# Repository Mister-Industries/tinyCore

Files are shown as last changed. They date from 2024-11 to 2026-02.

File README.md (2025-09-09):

# tinyCore - A Better Way to Learn ESP32

<div align="center">




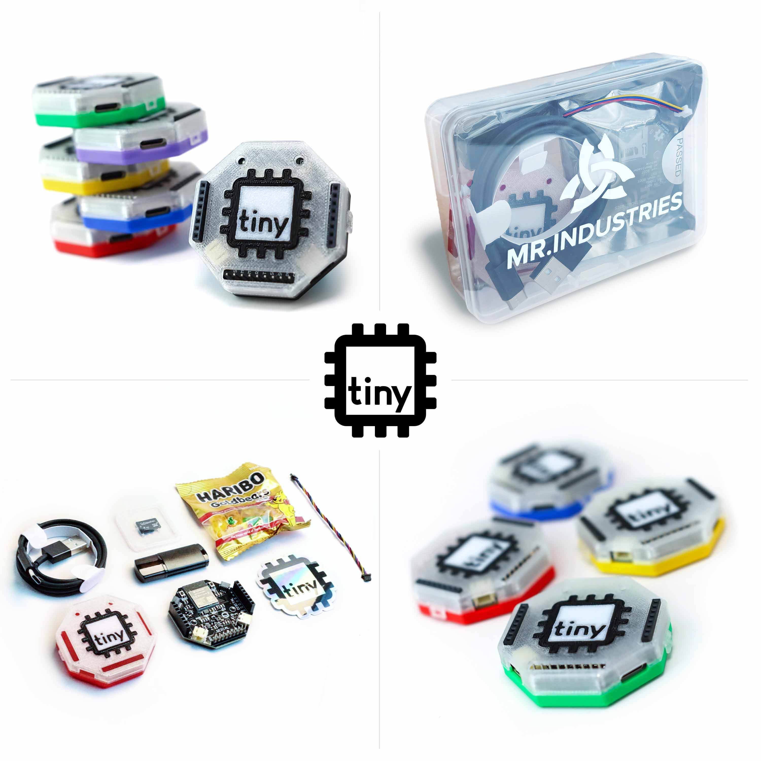
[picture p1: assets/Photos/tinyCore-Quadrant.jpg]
tinyCore Photos


</div>

ESP32-S3 chips are manufactured by Espressif®.
> Espressif® is a trademark of Espressif Systems (Shanghai) Co.Ltd (https://www.espressif.com/).

The tinyCore ESP32-S3 Board can be programmed with the Arduino® IDE.
> Arduino® is a trademark of Arduino LLC (https://www.arduino.cc/).

## Overview
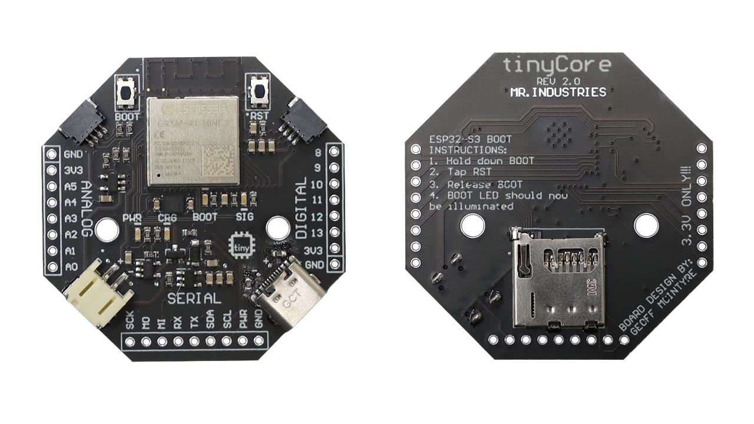
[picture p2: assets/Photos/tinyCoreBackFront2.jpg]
tinyCore Back/Front PCB


tinyCore is an engineering learning platform based around an "open-knowledge" microcontroller board designed to help educate individuals on the world of advanced embedded systems. tinyCore’s mission is to bridge the gap between undergrad and industry, equipping young professionals with the resources they need to build their portfolio and bring their ideas to life. 

## Pinout
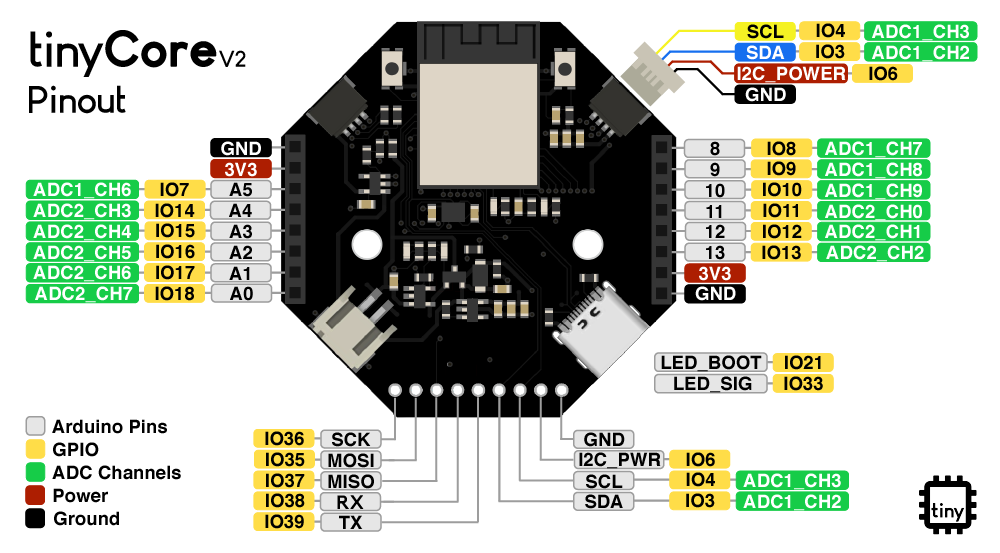
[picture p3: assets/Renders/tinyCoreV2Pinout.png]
tinyCore Pinout


### Key Features

- **Processor**: ESP32-S3 Mini Dual-Core No-PSRAM
- **Connectivity**: 
  - WiFi & Bluetooth LE
  - USB-C
  - 2x STEMMA/QWIIC I2C Connectors
  - Micro SD Card Slot
  - Built-in LSM6DSO IMU
- **Power**: 
  - USB-C powered
  - LiPo battery support with charging circuit
  - Low power sleep modes, Dedicated I2C PWR Rail
- **Dimensions**: 50mm x 50mm

## Getting Started

Open up the "START-HERE.pdf" document, or check out [our documentation](https://docs.mr.industries) to get started.

## Purchase

If you would like to get a tinyCore for yourself, please [visit our website](https://mr.industries/tiny-core) to purchase one!

For professors, tax-exempt organizations, or bulk orders (>10), please contact us through the following email address:
[support@mr.industries](mailto:support@mr.industries)

## Hardware

The complete hardware design files are available in the [hardware folder](https://github.com/Mister-Industries/tinyCore/tree/main/Hardware), including:
- Schematic files 
- PCB layout files (Altium/KiCad format)
- Bill of Materials (BOM)
- Manufacturing files (Gerber)
- Assembly instructions

## Development

### Contributing

We welcome contributions! Please see our [Contributing Guide](CONTRIBUTING.md) for details on:
- Code style guidelines
- Development workflow
- Testing requirements
- Pull request process

## Community

- [Discord Server](https://discord.gg/hvJZhwfQsF)
- [Bluesky](https://bsky.app/profile/mr.industries)

## License

This project is licensed under the MIT License - see the [LICENSE](LICENSE) file for details.

## Acknowledgments
The tinyCore project thrives thanks to the generous support of our manufacturing and development partners:
### --- PCBWay ---

PCBWay provides exceptional PCB manufacturing services and has been instrumental in bringing tinyCore to life through their reliable prototyping capabilities. You can order our open-source designs directly from [their website](https://www.pcbway.com/project/shareproject/iota_The_Open_Source_Advanced_IoT_Learning_Platform_12776757.html)

Special thanks to:
- The Adafruit team for inspiration
- All of our open source contributors
- "Prof. Eric Bogatin, Prof. Chris Coulston, Tyler Watts, Chaz Havens and countless others who inspired me to create fantastic things." - Geoff M.

## Support

MR.INDUSTRIES offers comprehensive technical support for everyone in our tinyCommunity:

* Help with understanding documentation and setup challenges
* Replacement parts for defective components
* Expert guidance for your tinyCore projects
* Weekly "Office Hours" every Thursday at 4:30 MST on [Discord Server](https://discord.gg/hvJZhwfQsF)
  * Get 1-1 help from our engineers via Discord voice
* Active community support through our [Discord](https://discord.gg/hvJZhwfQsF)

## Star History

Star History Chart (https://www.star-history.com/#Mister-Industries/tinyCore&Date)

You can also send us an email to:
[support@mr.industries](mailto:support@mr.industries)

**Our team is committed to helping you succeed with your project every step of the way.**

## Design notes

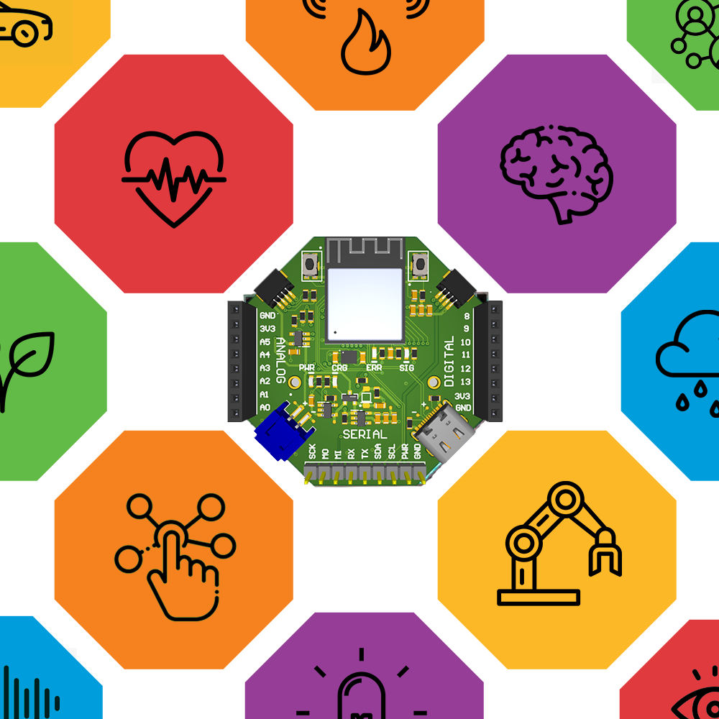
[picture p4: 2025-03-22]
assets/Renders/IotaKit.png

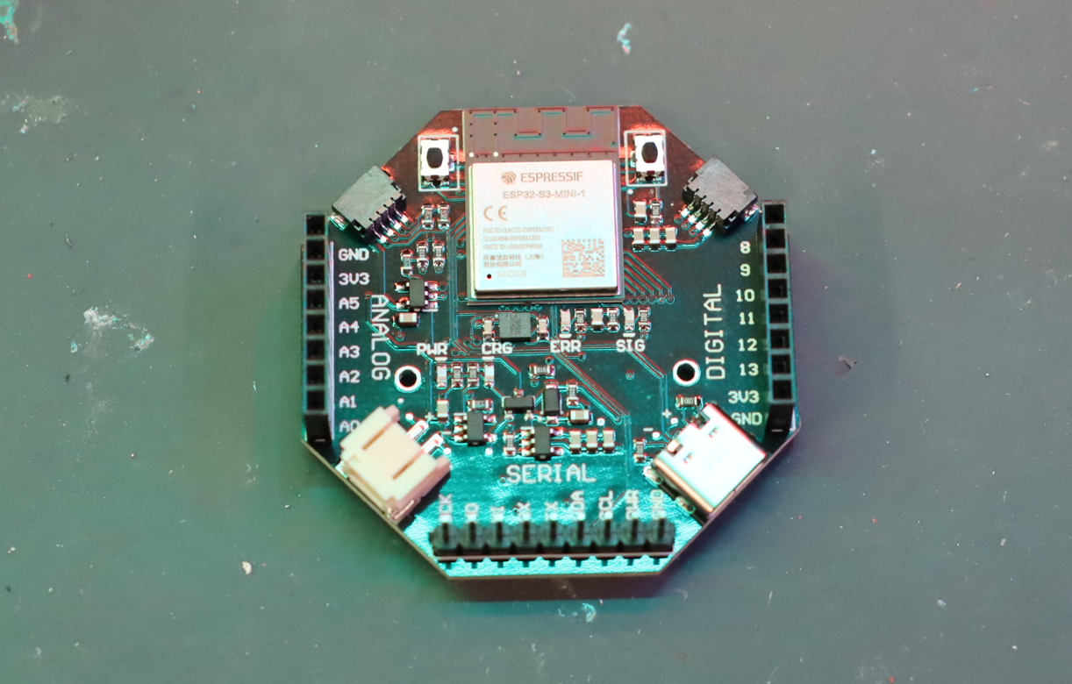
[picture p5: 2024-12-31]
assets/Photos/image.png

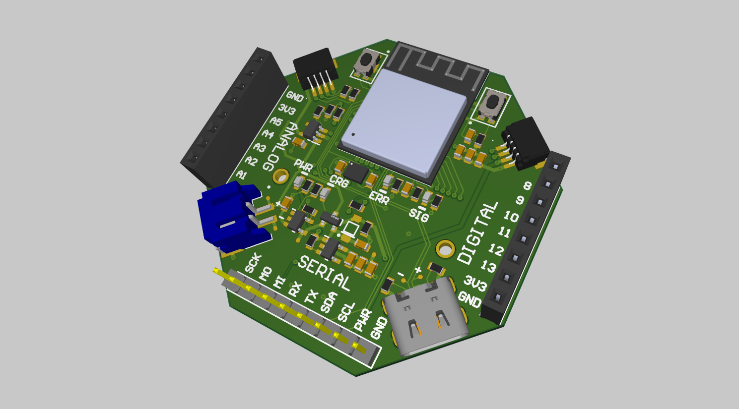
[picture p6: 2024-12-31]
assets/Renders/IotaCoreRenderWide.png

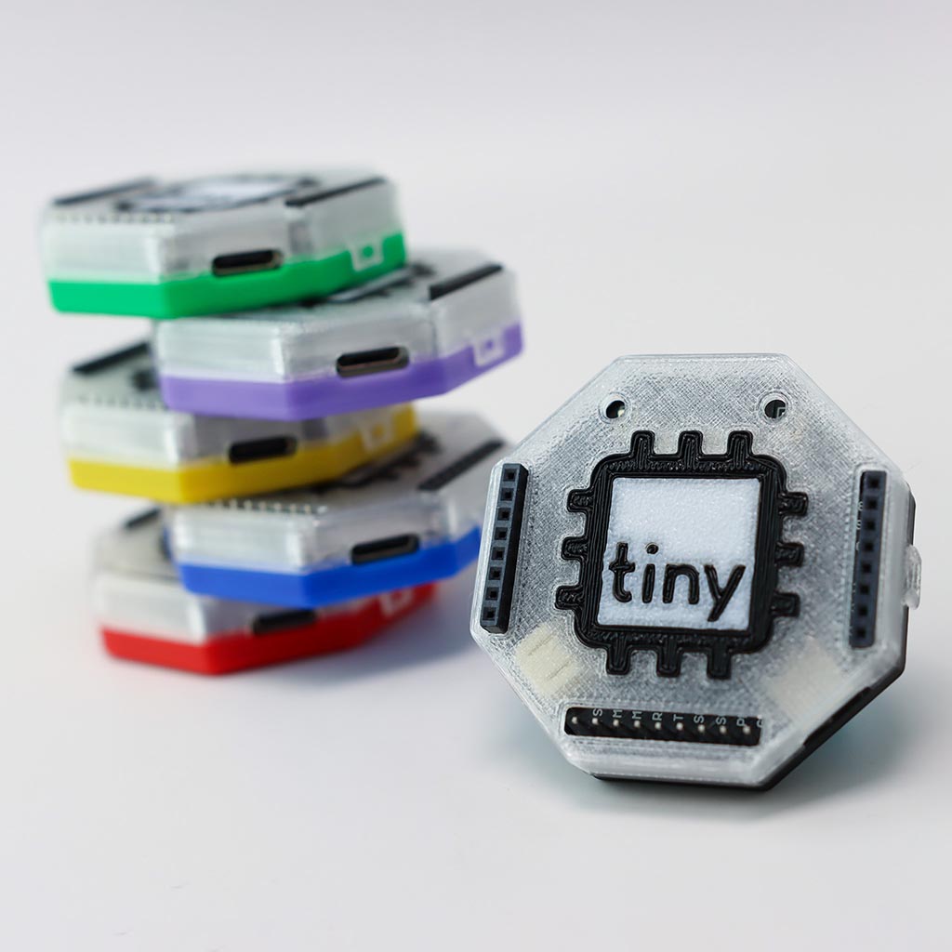
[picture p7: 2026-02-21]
assets/Photos/tinyCore-store-1.jpg

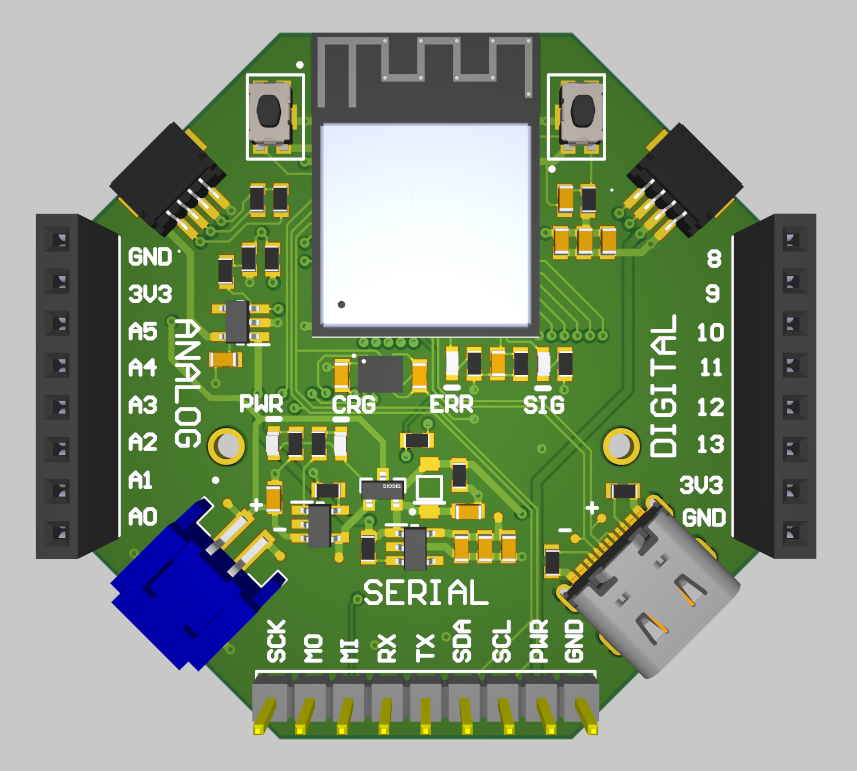
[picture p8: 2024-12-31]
assets/Renders/TopDown.png

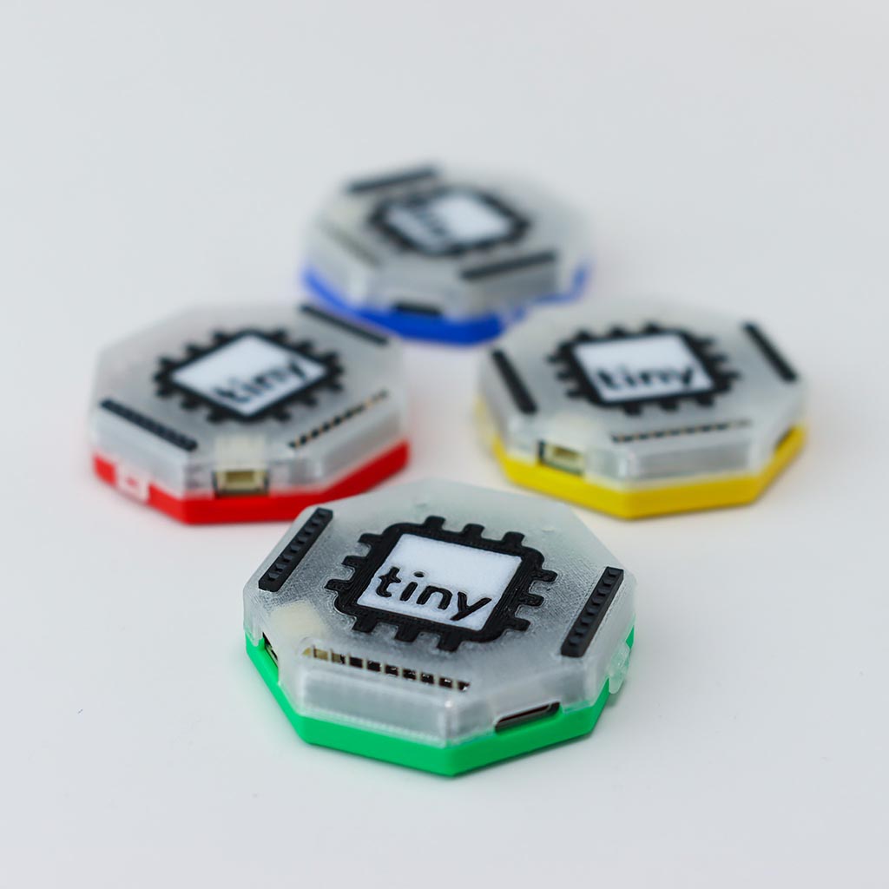
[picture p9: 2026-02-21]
assets/Photos/tinyCore-store-6.jpg

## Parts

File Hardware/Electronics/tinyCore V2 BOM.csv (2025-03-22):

Comment | Description | Designator | Footprint | LibRef | Quantity
LSM6DSOTR | DFD PROTECTION & FILTER | B1 | LSM6DSOTR | CMP-084-000000-2 | 1
AP2112K-3.3TRG1 | 600mA 3.3V LDO Regulator Enable SOT23-5 DiodesZetex AP2112K-3.3TRG1, LDO Voltage Regulator, 3.3 V +/-1.5%, 2.5 6 Vin, 5-Pin SOT-23 | B2, B4 | SOT95P270X145-5N | CMP-007-000001-1 | 2
MCP73831T-2ACI_OT | Li-Ion Charge Controller 4.2V SOT23-5 | B3 | SOT95P270X145-5N | CMP-009-000000-1 | 1
HSMA-C190 | LED Uni-Color Amber, 60 mW, 20 mA, -40 to 85 degC, 2-Pin SMD, RoHS, Tape and Reel | BOOT, CRG, PWR, SIG | AVAG-HSMX-C190_V | CMP-007-00011-2 | 4
Capacitor 10 uF +/- 0.25 uF 50 V 0603 | Chip Capacitor, 10 uF, +/- 0.25 uF, 50 V, 0603 (1608 Metric) | C1, C2, C3, C4, C7, C8, C9, C10, C11, C12, C13 | CAPC1608X87X35NL15T15 | CMP-001-00012-6 | 11
Capacitor 0.1 uF 50 V 0603 | Chip Capacitor, 0.1 uF, +/- 0.25 pF, 50 V, 0603 (1608 Metric) | C5, C6 | CAPC1608X87X35NL15T15 | CMP-001-00012-6 | 2
MBR120 | Diode | D1 | ONSC-SOD-123FL-2-498-01_V | CMP-004-00031-1 | 1
2908-05WB-MG | CONN MICRO SD CARD PUSH-PUSH R/A | J1 | FP-2908-05WB-MG-MFG | CMP-019-00049-1 | 1
USB4105-GF-A | USB-C 16-Pin Component | J5 | USB4105-GF-A | CMP-013-000000-1 | 1
4208 | Adafruit Accessories JST SH 4-pin Right Angle Connector (10-pack) - Qwiic Compatible | J6, J7 | 4390 | CMP-002-00080-4 | 2
CN-1P-2M-R2 |  | P1 | JST- S2B-PH-SM4-TB(LF)(SN)-2_V | CMP-005-000001-1 | 1
DMG2305UX-7 | Power Field-Effect Transistor, 4.2A I(D), 20V, 0.052ohm, 1-Element, P-Channel, Silicon, Metal-oxide Semiconductor FET | Q1 | FP-SOT23-MFG | CMP001-1 | 1
Resistor 100k +/-1% 0603 100 mW | Chip Resistor, 100 KOhm, +/- 1%, 0.1 W, -55 to 155 degC, 0603 (1608 Metric) | R1, R2, R7, R8, R9, R12 | RESC1608X55X25ML10T15 | CMP-009-00023-5 | 6
Resistor 4.7k +/-1% 0603 100 mW | Chip Resistor, 4.7 KOhm, +/- 1%, 0.1 W, -55 to 155 degC, 0603 (1608 Metric) | R3, R10, R13, R16, R17 | RESC1608X55X25ML10T15 | CMP-009-00023-5 | 5
Resistor 1k +/-1% 0603 100 mW | Chip Resistor, 1 KOhm, +/- 1%, 0.1 W, -55 to 155 degC, 0603 (1608 Metric) | R4, R5, R6, R11 | RESC1608X55X25ML10T15 | CMP-009-00023-5 | 4
Resistor 5.1k +/-1% 0603 100 mW | Chip Resistor, 5.1 KOhm, +/- 1%, 0.1 W, -55 to 155 degC, 0603 (1608 Metric) | R14, R15 | RESC1608X55X25ML10T15 | CMP-009-00023-5 | 2
KMR211GLFS |  | SW1, SW2 | FP-KMR211GLFS-MFG | CMP-011-00013-6 | 2
ESP32-S3-MINI-1-N8 | SMD module, ESP32-S3FN8, 8 MB SPI flash, PCB antenna | U1 | ESP32-S3-MINI-1-N8 | CMP-010-000006-5 | 1

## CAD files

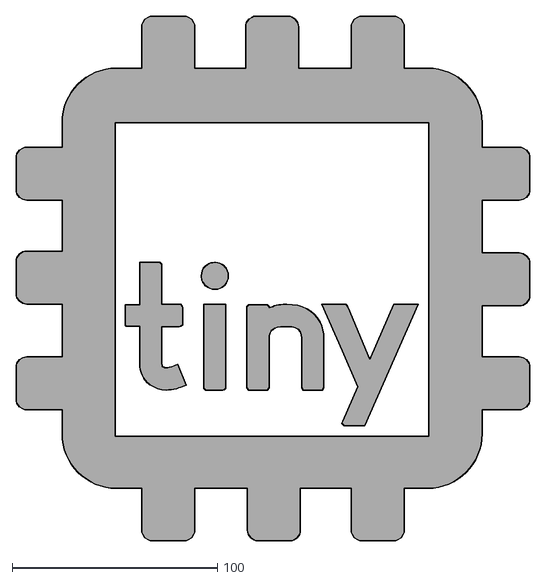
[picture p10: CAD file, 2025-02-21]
assets/Branding/tinyCore.dxf
250.1 x 255.3

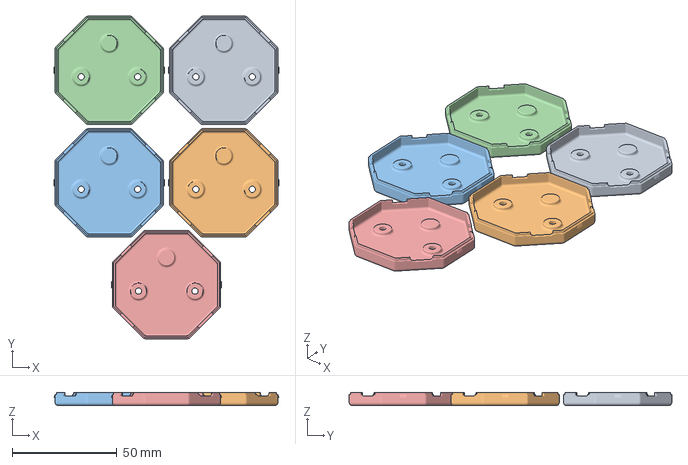
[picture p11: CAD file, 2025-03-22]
Hardware/Enclosure/Bambu/Enclosure-Bottom.3mf
107.6 x 154.3 x 6.30 mm
BottomEnclosureTabs.STL x 5

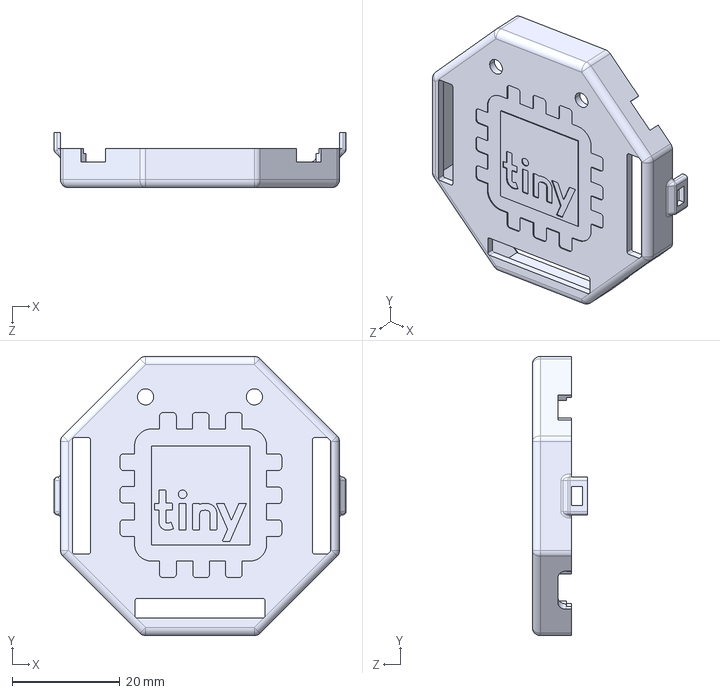
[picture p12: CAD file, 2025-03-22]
Hardware/Enclosure/STEP/Enclosure-Top.STEP
54.2 x 51.8 x 10.3 mm

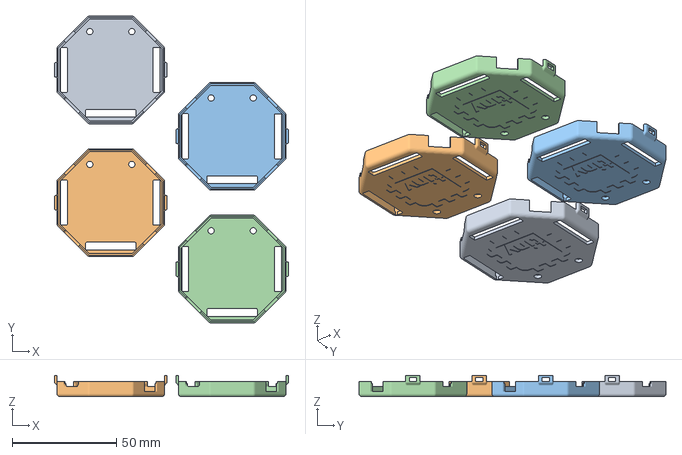
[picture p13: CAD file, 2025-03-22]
Hardware/Enclosure/Bambu/Enclosure-Top.3mf
112.5 x 147.5 x 10.3 mm
TopEnclosureLogo.STL x 4

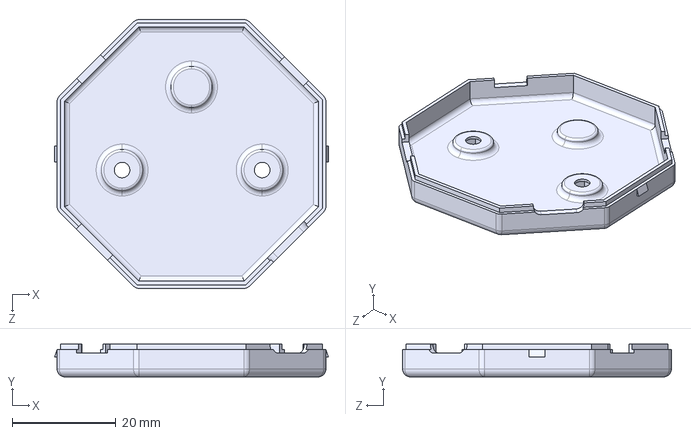
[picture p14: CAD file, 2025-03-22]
Hardware/Enclosure/STEP/Enclosure-Bottom.STEP
52.8 x 6.30 x 51.8 mm

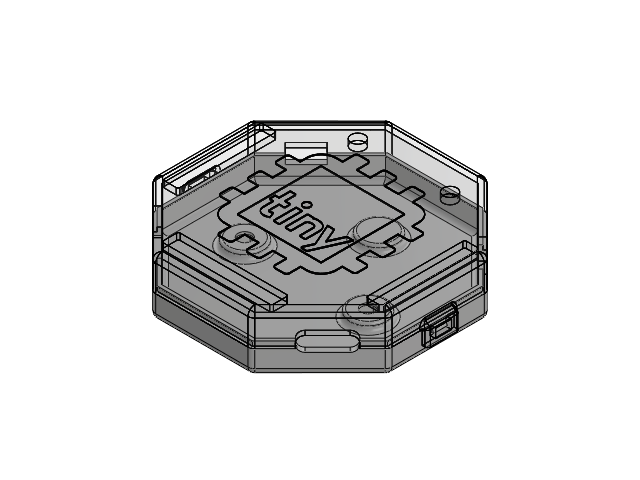
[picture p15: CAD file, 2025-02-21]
Hardware/Enclosure/SolidWorks/tinyCore.SLDASM
BottomEnclosure
TopEnclosure

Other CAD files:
Hardware/Enclosure/STL/Enclosure-Bottom.STL
Hardware/Enclosure/STL/Enclosure-Top.STL
Hardware/Enclosure/SolidWorks/Enclosure-Bottom.SLDPRT
Hardware/Enclosure/SolidWorks/Enclosure-Top.SLDPRT

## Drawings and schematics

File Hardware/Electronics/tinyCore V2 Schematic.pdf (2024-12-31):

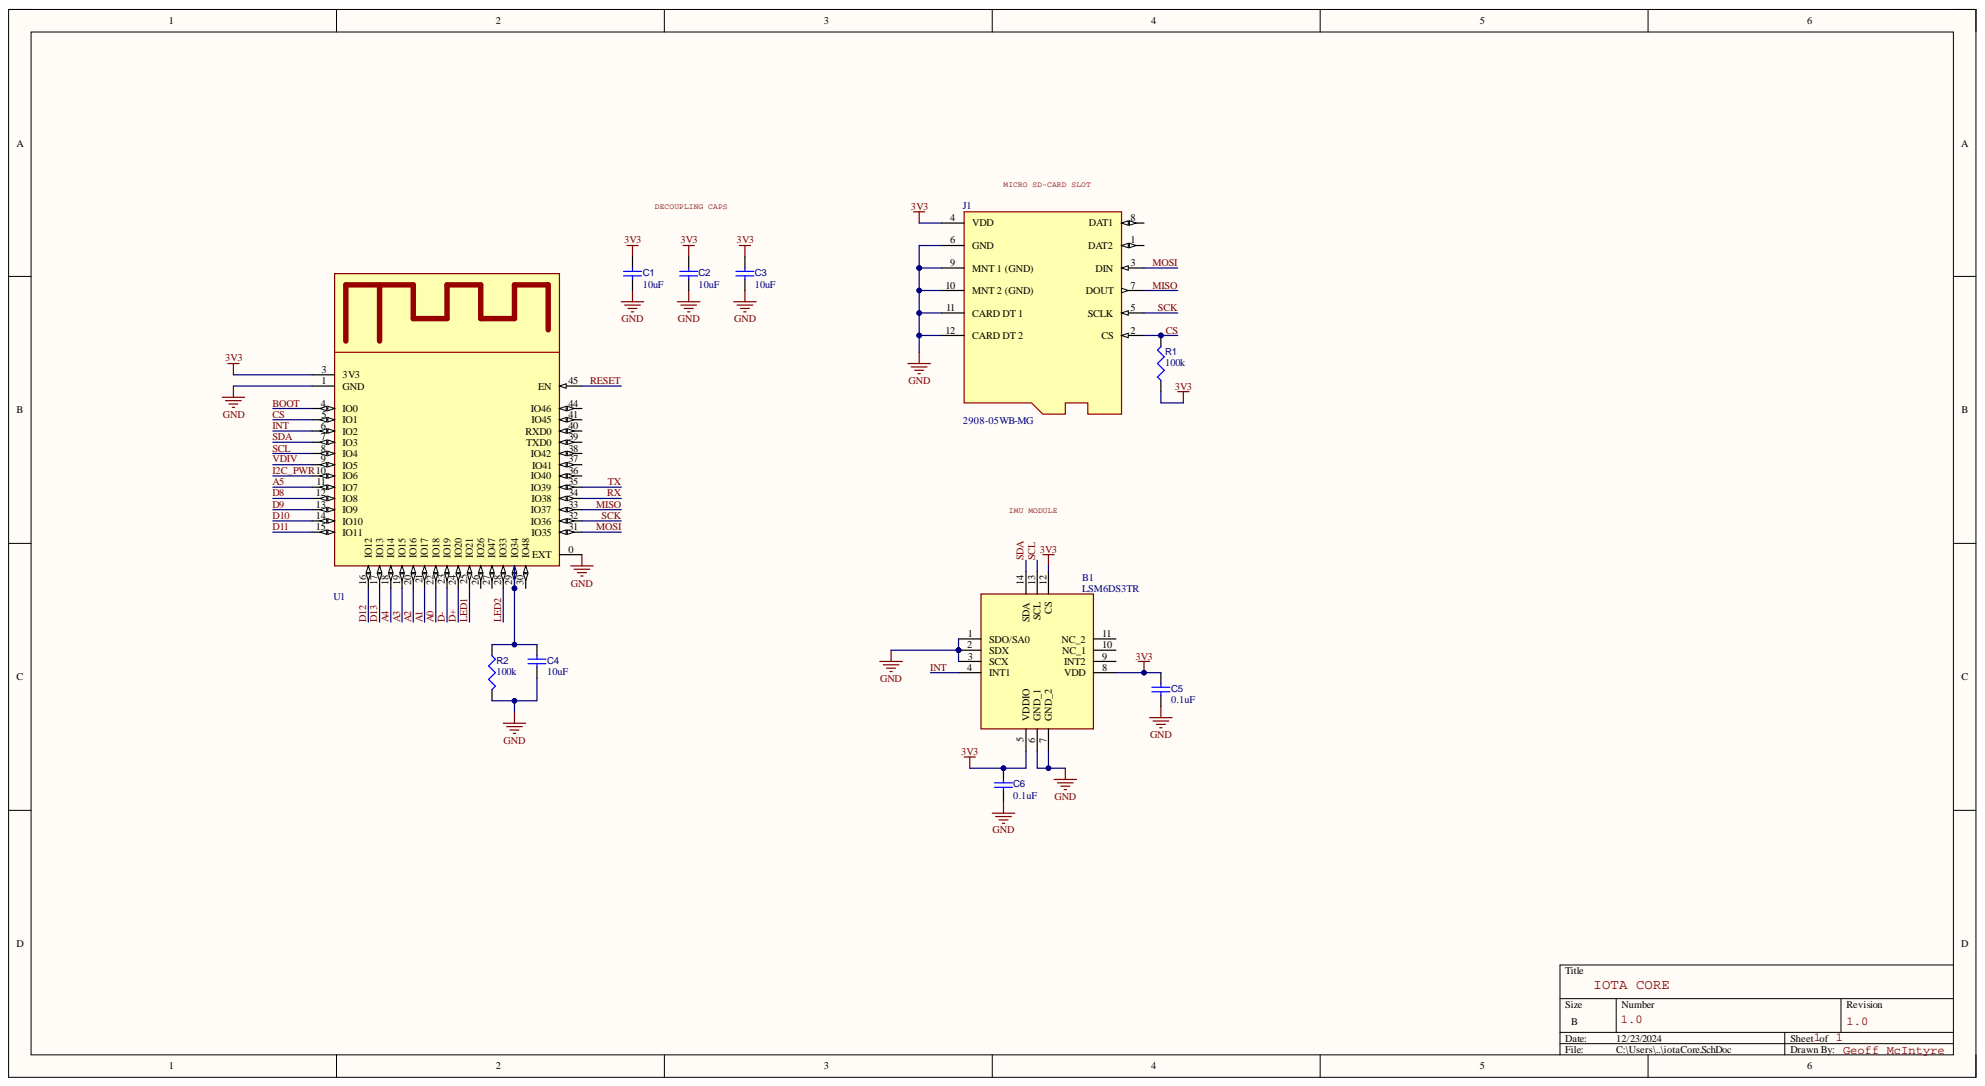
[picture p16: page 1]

te : 1 2 / 2 3 /2 0 2 4 | 1 1 S h e e t o f
Fi l e : C : \ U s e r s \ . . \ i o t a C o re . S c hDo c | D r a w n B y : Geoff McIntyre

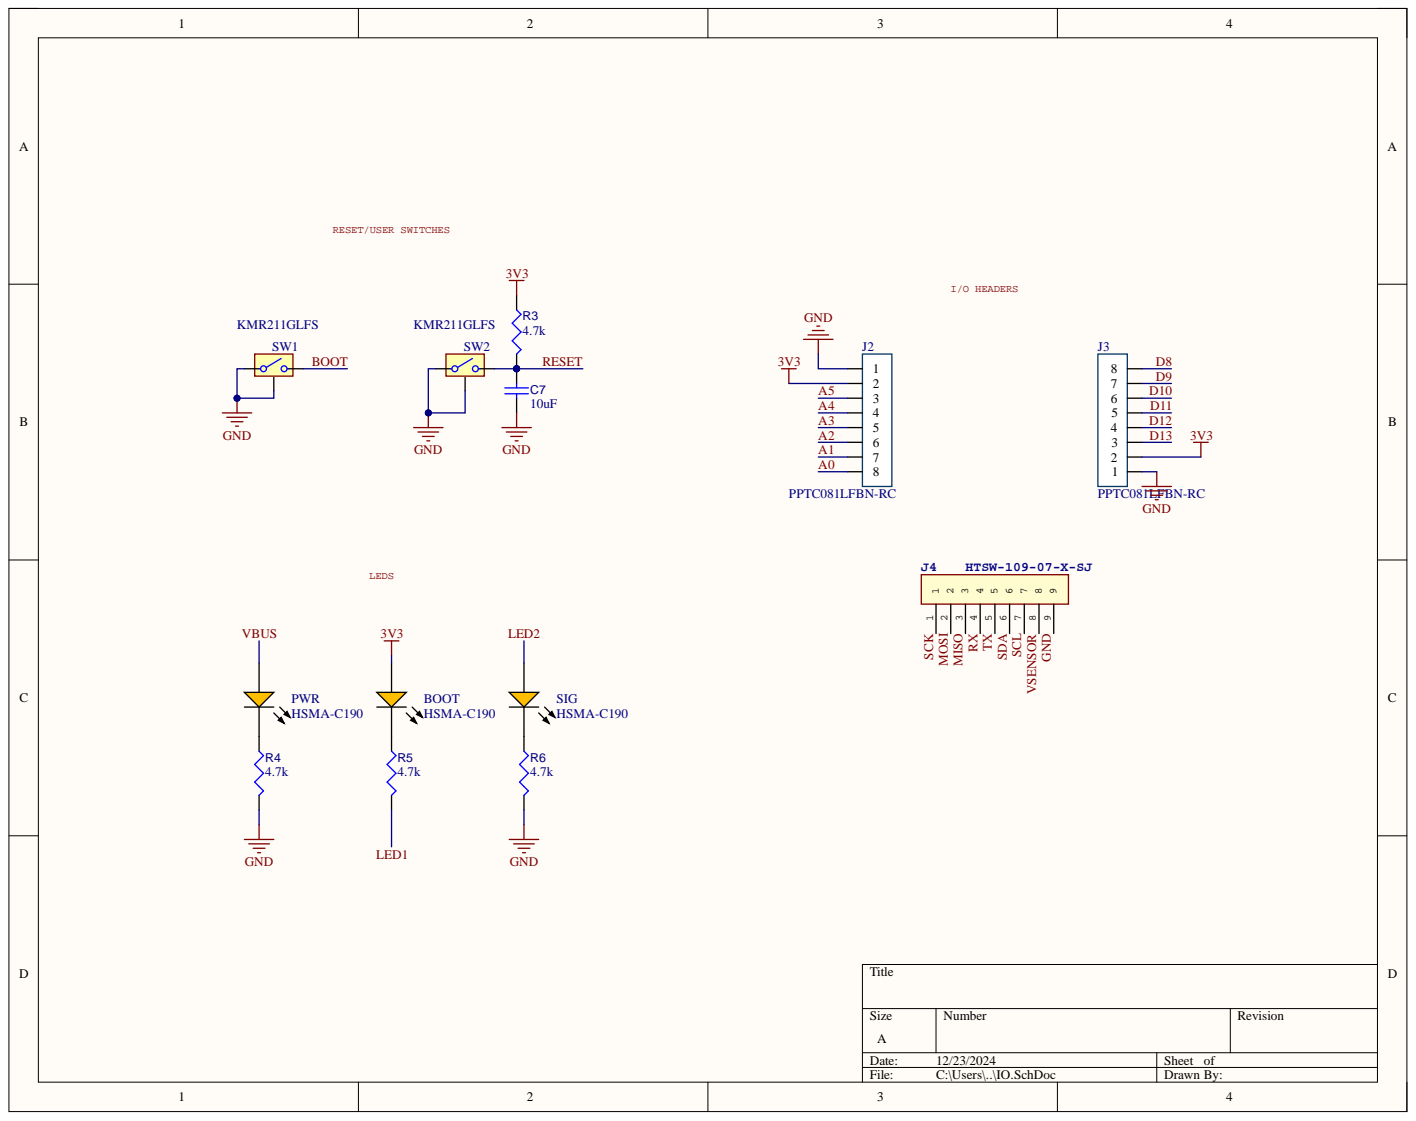
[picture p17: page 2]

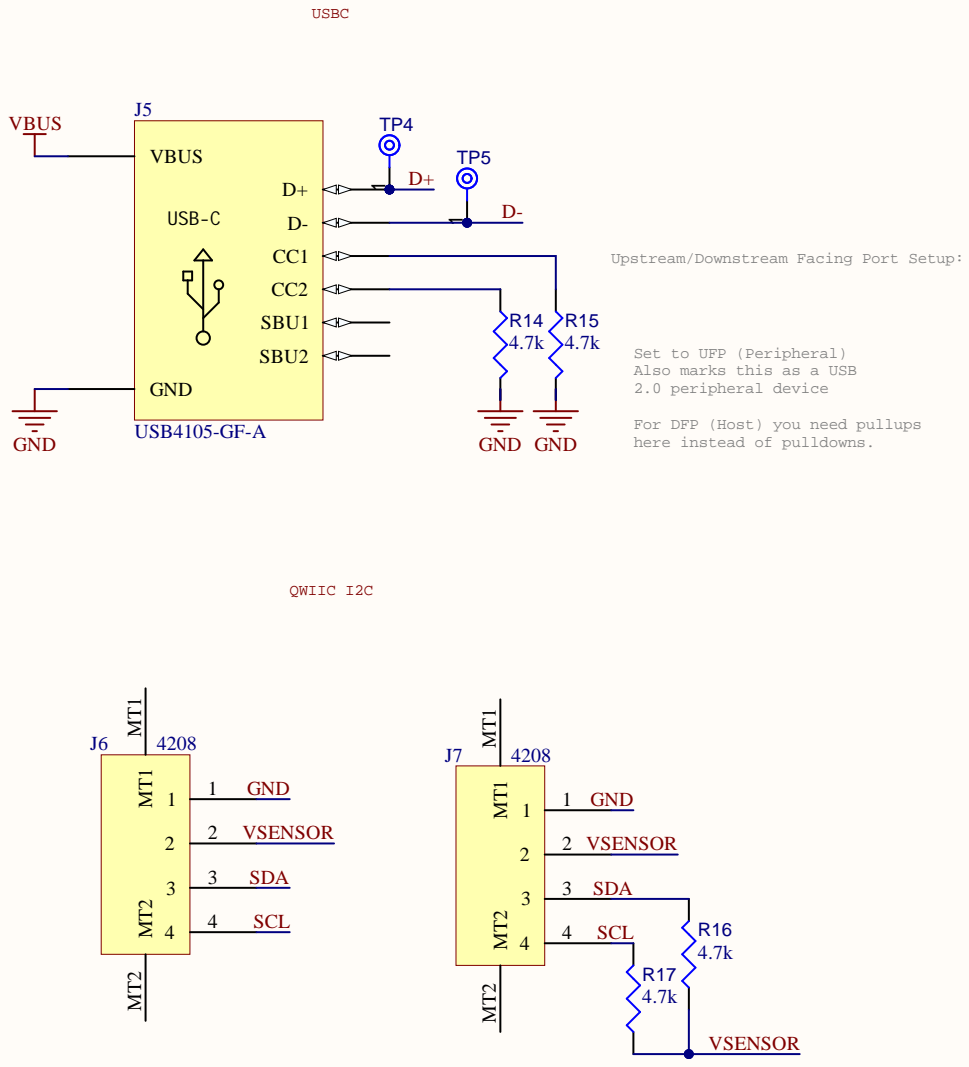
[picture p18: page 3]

Upstream/Downstream Facing Port Setup:

Set to UFP (Peripheral)
Also marks this as a USB
2.0 peripheral device

For DFP (Host) you need pullups
here instead of pulldowns.

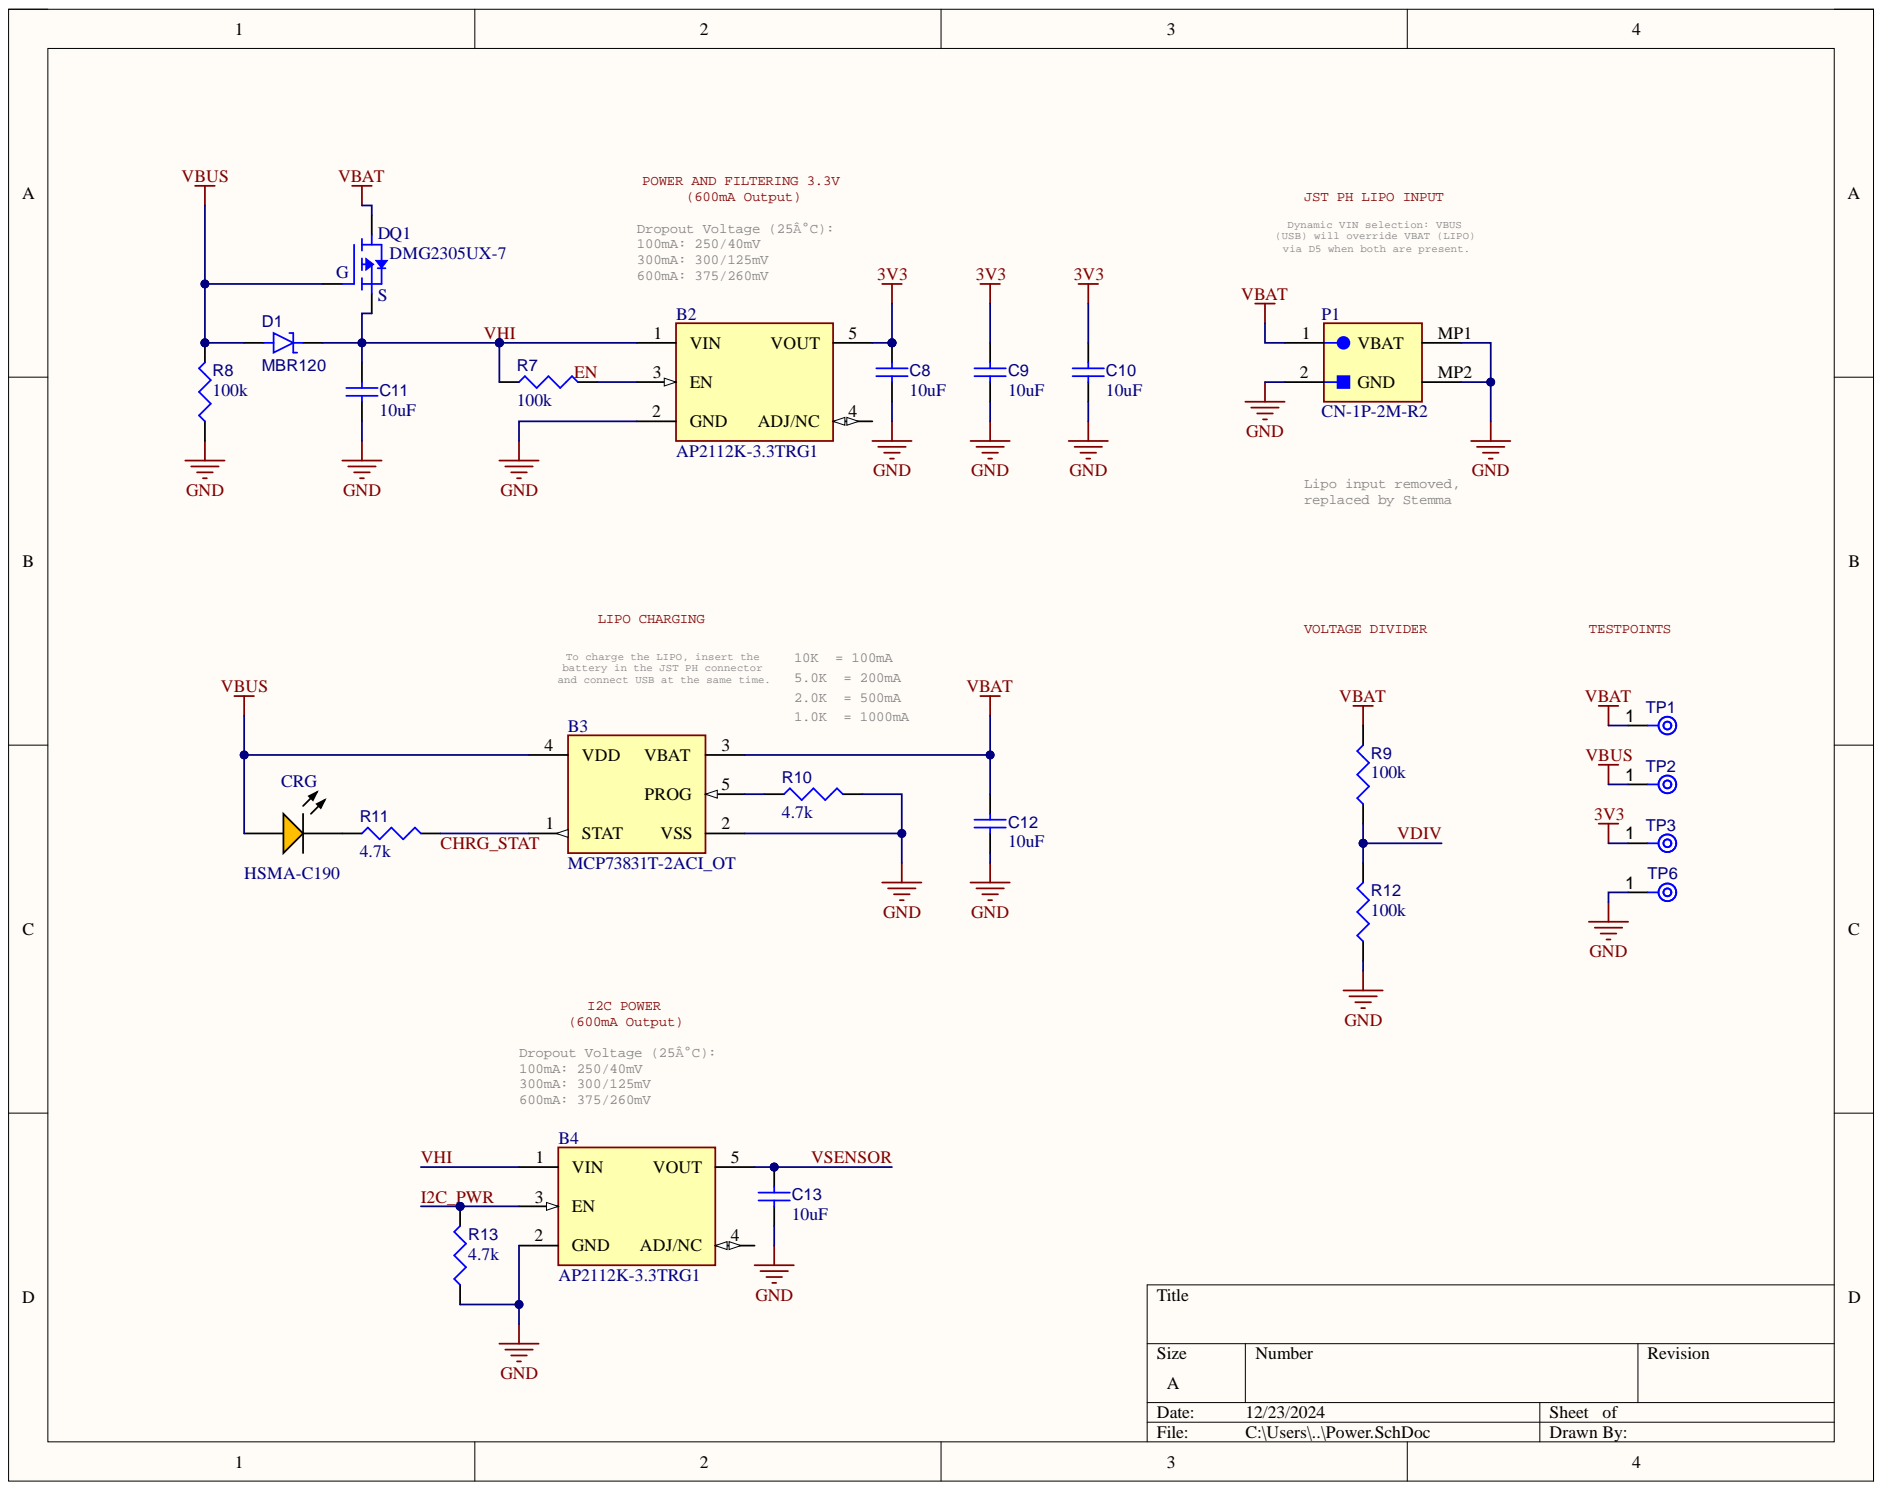
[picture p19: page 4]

JST PH LIPO INPUT

Dynamic VIN selection: VBUS
(USB) will override VBAT (LIPO)
via D5 when both are present.

To charge the LIPO, insert the
battery in the JST PH connector
and connect USB at the same time.

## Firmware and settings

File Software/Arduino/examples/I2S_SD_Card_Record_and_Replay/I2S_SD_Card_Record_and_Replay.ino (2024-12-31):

#include <Arduino.h>
#include "FS.h"
#include "SD.h"
#include "SPI.h"
#include <driver/i2s.h>

// Pin Definitions
// Microphone (SPH0645)
#define I2S_MIC_SCK     8
#define I2S_MIC_WS      9
#define I2S_MIC_SD      10

// Speaker
#define I2S_SPKR_BCLK   8
#define I2S_SPKR_LRC    9
#define I2S_SPKR_DIN    10

// Constants for recording
const int RECORD_TIME = 5;  // seconds to record
const int SAMPLE_RATE = 44100;
const int SAMPLE_BITS = 32;
const int WAV_HEADER_SIZE = 44;
const char* RECORD_FILE = "/recording.wav";
const int BINARY_BUFFER_SIZE = 1024;

// Global flag to track I2S state
bool i2s_initialized = false;

// WAV header structure
struct WavHeader {
    char riff[4] = {'R', 'I', 'F', 'F'};
    uint32_t fileSize = 0;
    char wave[4] = {'W', 'A', 'V', 'E'};
    char fmt[4] = {'f', 'm', 't', ' '};
    uint32_t fmtSize = 16;
    uint16_t audioFormat = 1;
    uint16_t numChannels = 1;
    uint32_t sampleRate = SAMPLE_RATE;
    uint32_t byteRate = SAMPLE_RATE * 2;
    uint16_t blockAlign = 2;
    uint16_t bitsPerSample = 16;
    char data[4] = {'d', 'a', 't', 'a'};
    uint32_t dataSize = 0;
};

void cleanup_i2s() {
    if (i2s_initialized) {
        i2s_stop(I2S_NUM_0);
        i2s_driver_uninstall(I2S_NUM_0);
        i2s_initialized = false;
        delay(100);
    }
}

void i2s_mic_init() {
    cleanup_i2s();
    
    // Configuration for SPH0645
    i2s_config_t i2s_config = {
        .mode = (i2s_mode_t)(I2S_MODE_MASTER | I2S_MODE_RX),
        .sample_rate = SAMPLE_RATE,
        .bits_per_sample = I2S_BITS_PER_SAMPLE_32BIT,
        .channel_format = I2S_CHANNEL_FMT_ONLY_LEFT,
        .communication_format = I2S_COMM_FORMAT_STAND_I2S,
        .intr_alloc_flags = ESP_INTR_FLAG_LEVEL1,
        .dma_buf_count = 4,
        .dma_buf_len = 1024,
        .use_apll = false,
        .tx_desc_auto_clear = false,
        .fixed_mclk = 0
    };
    
    i2s_pin_config_t pin_config = {
        .mck_io_num = I2S_PIN_NO_CHANGE,
        .bck_io_num = I2S_MIC_SCK,
        .ws_io_num = I2S_MIC_WS,
        .data_out_num = I2S_PIN_NO_CHANGE,
        .data_in_num = I2S_MIC_SD
    };
    
    esp_err_t err = i2s_driver_install(I2S_NUM_0, &i2s_config, 0, NULL);
    if (err != ESP_OK) {
        Serial.printf("Failed to install I2S driver for mic: %d\n", err);
        return;
    }
    
    err = i2s_set_pin(I2S_NUM_0, &pin_config);
    if (err != ESP_OK) {
        Serial.printf("Failed to set I2S pins for mic: %d\n", err);
        return;
    }
    
    i2s_initialized = true;
    delay(100);
}

void i2s_speaker_init() {
    cleanup_i2s();
    
    i2s_config_t i2s_config = {
        .mode = (i2s_mode_t)(I2S_MODE_MASTER | I2S_MODE_TX),
        .sample_rate = SAMPLE_RATE,
        .bits_per_sample = I2S_BITS_PER_SAMPLE_16BIT,
        .channel_format = I2S_CHANNEL_FMT_ONLY_LEFT,
        .communication_format = I2S_COMM_FORMAT_STAND_I2S,
        .intr_alloc_flags = ESP_INTR_FLAG_LEVEL1,
        .dma_buf_count = 8,
        .dma_buf_len = 1024,
        .use_apll = false,
        .tx_desc_auto_clear = true,
        .fixed_mclk = 0
    };
    
    i2s_pin_config_t pin_config = {
        .mck_io_num = I2S_PIN_NO_CHANGE,
        .bck_io_num = I2S_SPKR_BCLK,
        .ws_io_num = I2S_SPKR_LRC,
        .data_out_num = I2S_SPKR_DIN,
        .data_in_num = I2S_PIN_NO_CHANGE
    };
    
    esp_err_t err = i2s_driver_install(I2S_NUM_0, &i2s_config, 0, NULL);
    if (err != ESP_OK) {
        Serial.printf("Failed to install I2S driver for speaker: %d\n", err);
        return;
    }
    
    err = i2s_set_pin(I2S_NUM_0, &pin_config);
    if (err != ESP_OK) {
        Serial.printf("Failed to set I2S pins for speaker: %d\n", err);
        return;
    }
    
    i2s_initialized = true;
    delay(100);
}

void writeWavHeader(File file, size_t dataSize) {
    WavHeader header;
    header.fileSize = dataSize + WAV_HEADER_SIZE - 8;
    header.dataSize = dataSize;
    file.write((const uint8_t*)&header, WAV_HEADER_SIZE);
}

void startRecording() {
    Serial.println("Starting recording...");
    
    i2s_mic_init();
    
    if (!i2s_initialized) {
        Serial.println("Failed to initialize I2S for recording");
        return;
    }
    
    if (SD.exists(RECORD_FILE)) {
        SD.remove(RECORD_FILE);
    }
    
    File file = SD.open(RECORD_FILE, FILE_WRITE);
    if (!file) {
        Serial.println("Failed to open file for recording");
        return;
    }
    
    // Write placeholder header
    WavHeader header;
    file.write((const uint8_t*)&header, WAV_HEADER_SIZE);
    
    size_t bytesWritten = 0;
    unsigned long startTime = millis();
    int32_t samples[BINARY_BUFFER_SIZE/4];
    
    Serial.println("Recording...");
    
    while ((millis() - startTime) < (RECORD_TIME * 1000)) {
        size_t bytesRead = 0;
        esp_err_t result = i2s_read(I2S_NUM_0, samples, sizeof(samples), &bytesRead, portMAX_DELAY);
        
        if (result == ESP_OK && bytesRead > 0) {
            // Process SPH0645 data: 24-bit signed integer in MSB format
            int16_t converted[BINARY_BUFFER_SIZE/8];
            for (int i = 0; i < bytesRead/4; i++) {
                // Convert 24-bit to 16-bit with proper scaling
                converted[i] = (int16_t)(samples[i] >> 14);
            }
            file.write((const uint8_t*)converted, bytesRead/2);
            bytesWritten += bytesRead/2;
        }
    }
    
    // Update WAV header with final size
    file.seek(0);
    writeWavHeader(file, bytesWritten);
    file.close();
    
    cleanup_i2s();
    Serial.println("Recording finished!");
}

void playRecording() {
    Serial.println("Playing recording...");
    
    // Initialize speaker
    i2s_speaker_init();
    if (!i2s_initialized) {
        Serial.println("Failed to initialize I2S for playback");
        return;
    }
    
    // Open WAV file
    File file = SD.open(RECORD_FILE);
    if (!file) {
        Serial.println("Failed to open file for playback");
        return;
    }
    
    // Skip WAV header
    file.seek(WAV_HEADER_SIZE);
    
    // Read and play file
    uint8_t buffer[1024];
    size_t bytes_read;
    Serial.println("Starting playback...");
    
    while (file.available()) {
        bytes_read = file.read(buffer, sizeof(buffer));
        if (bytes_read > 0) {
            size_t bytes_written = 0;

            // Amplify the signal
            int16_t *samples = (int16_t*)buffer;
            for(int i=0; i < bytes_read/2; i++) {
              samples[i] = samples[i] * 4;  // Multiply by 2-8 for more volume
            }
            
            esp_err_t result = i2s_write(I2S_NUM_0, buffer, bytes_read, &bytes_written, portMAX_DELAY);
            if (result != ESP_OK) {
                Serial.printf("Failed to write I2S data: %d\n", result);
            }
        }
    }
    
    file.close();
    cleanup_i2s();
    Serial.println("Playback finished!");
}

void setup() {
    Serial.begin(115200);
    while (!Serial) delay(10);
    
    Serial.println("Initializing...");
    
    // Initialize SD card
    if (!SD.begin()) {
        Serial.println("Card Mount Failed");
        return;
    }
    
    // Make sure I2S is clean at startup
    cleanup_i2s();
    
    Serial.println("Ready! Send 'R' to start recording.");
}

void loop() {
    if (Serial.available()) {
        char cmd = Serial.read();
        if (cmd == 'R' || cmd == 'r') {
            startRecording();
            delay(500);
            playRecording();
        }
    }
}

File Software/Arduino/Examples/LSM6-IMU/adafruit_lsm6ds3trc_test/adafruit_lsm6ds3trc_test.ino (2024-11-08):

// Basic demo for accelerometer/gyro readings from Adafruit LSM6DS3TR-C

#include <Adafruit_LSM6DS3TRC.h>

// For SPI mode, we need a CS pin
#define LSM_CS 10
// For software-SPI mode we need SCK/MOSI/MISO pins
#define LSM_SCK 13
#define LSM_MISO 12
#define LSM_MOSI 11

Adafruit_LSM6DS3TRC lsm6ds3trc;

void setup(void) {
  pinMode(6, OUTPUT);
  digitalWrite(6, HIGH);
  
  Serial.begin(115200);
  while (!Serial)
    delay(10);

  Serial.println("Starting I2C initialization...");
  Wire.begin(3, 4);
  delay(100);  // Give I2C time to stabilize

  Serial.println("Scanning for I2C devices...");
  for (byte address = 1; address < 127; address++) {
    Wire.beginTransmission(address);
    byte error = Wire.endTransmission();
    if (error == 0) {
      Serial.print("I2C device found at address 0x");
      if (address < 16) {
        Serial.print("0");
      }
      Serial.println(address, HEX);
      
      // If this is our LSM6DS3TR-C address, try reading WHO_AM_I register
      if (address == 0x6A) {
        Wire.beginTransmission(0x6A);
        Wire.write(0x0F);  // WHO_AM_I register address
        Wire.endTransmission(false);
        Wire.requestFrom(0x6A, 1);
        if (Wire.available()) {
          byte whoAmI = Wire.read();
          Serial.print("WHO_AM_I register value: 0x");
          Serial.println(whoAmI, HEX);
          // Should be 0x6A for LSM6DS3TR-C
        }
      }
    }
  }

  Serial.println("Attempting to initialize LSM6DS3TR-C...");
  if (!lsm6ds3trc.begin_I2C()) {
    Serial.println("Failed to find LSM6DS3TR-C chip");
    Serial.println("Check your wiring!");
    while (1) {
      delay(10);
    }
  }

  Serial.println("LSM6DS3TR-C Found!");

  // lsm6ds3trc.setAccelRange(LSM6DS_ACCEL_RANGE_2_G);
  Serial.print("Accelerometer range set to: ");
  switch (lsm6ds3trc.getAccelRange()) {
  case LSM6DS_ACCEL_RANGE_2_G:
    Serial.println("+-2G");
    break;
  case LSM6DS_ACCEL_RANGE_4_G:
    Serial.println("+-4G");
    break;
  case LSM6DS_ACCEL_RANGE_8_G:
    Serial.println("+-8G");
    break;
  case LSM6DS_ACCEL_RANGE_16_G:
    Serial.println("+-16G");
    break;
  }

  // lsm6ds3trc.setGyroRange(LSM6DS_GYRO_RANGE_250_DPS);
  Serial.print("Gyro range set to: ");
  switch (lsm6ds3trc.getGyroRange()) {
  case LSM6DS_GYRO_RANGE_125_DPS:
    Serial.println("125 degrees/s");
    break;
  case LSM6DS_GYRO_RANGE_250_DPS:
    Serial.println("250 degrees/s");
    break;
  case LSM6DS_GYRO_RANGE_500_DPS:
    Serial.println("500 degrees/s");
    break;
  case LSM6DS_GYRO_RANGE_1000_DPS:
    Serial.println("1000 degrees/s");
    break;
  case LSM6DS_GYRO_RANGE_2000_DPS:
    Serial.println("2000 degrees/s");
    break;
  case ISM330DHCX_GYRO_RANGE_4000_DPS:
    break; // unsupported range for the DS33
  }

  // lsm6ds3trc.setAccelDataRate(LSM6DS_RATE_12_5_HZ);
  Serial.print("Accelerometer data rate set to: ");
  switch (lsm6ds3trc.getAccelDataRate()) {
  case LSM6DS_RATE_SHUTDOWN:
    Serial.println("0 Hz");
    break;
  case LSM6DS_RATE_12_5_HZ:
    Serial.println("12.5 Hz");
    break;
  case LSM6DS_RATE_26_HZ:
    Serial.println("26 Hz");
    break;
  case LSM6DS_RATE_52_HZ:
    Serial.println("52 Hz");
    break;
  case LSM6DS_RATE_104_HZ:
    Serial.println("104 Hz");
    break;
  case LSM6DS_RATE_208_HZ:
    Serial.println("208 Hz");
    break;
  case LSM6DS_RATE_416_HZ:
    Serial.println("416 Hz");
    break;
  case LSM6DS_RATE_833_HZ:
    Serial.println("833 Hz");
    break;
  case LSM6DS_RATE_1_66K_HZ:
    Serial.println("1.66 KHz");
    break;
  case LSM6DS_RATE_3_33K_HZ:
    Serial.println("3.33 KHz");
    break;
  case LSM6DS_RATE_6_66K_HZ:
    Serial.println("6.66 KHz");
    break;
  }

  // lsm6ds3trc.setGyroDataRate(LSM6DS_RATE_12_5_HZ);
  Serial.print("Gyro data rate set to: ");
  switch (lsm6ds3trc.getGyroDataRate()) {
  case LSM6DS_RATE_SHUTDOWN:
    Serial.println("0 Hz");
    break;
  case LSM6DS_RATE_12_5_HZ:
    Serial.println("12.5 Hz");
    break;
  case LSM6DS_RATE_26_HZ:
    Serial.println("26 Hz");
    break;
  case LSM6DS_RATE_52_HZ:
    Serial.println("52 Hz");
    break;
  case LSM6DS_RATE_104_HZ:
    Serial.println("104 Hz");
    break;
  case LSM6DS_RATE_208_HZ:
    Serial.println("208 Hz");
    break;
  case LSM6DS_RATE_416_HZ:
    Serial.println("416 Hz");
    break;
  case LSM6DS_RATE_833_HZ:
    Serial.println("833 Hz");
    break;
  case LSM6DS_RATE_1_66K_HZ:
    Serial.println("1.66 KHz");
    break;
  case LSM6DS_RATE_3_33K_HZ:
    Serial.println("3.33 KHz");
    break;
  case LSM6DS_RATE_6_66K_HZ:
    Serial.println("6.66 KHz");
    break;
  }

  lsm6ds3trc.configInt1(false, false, true); // accelerometer DRDY on INT1
  lsm6ds3trc.configInt2(false, true, false); // gyro DRDY on INT2
}

void loop() {
  // Get a new normalized sensor event
  sensors_event_t accel;
  sensors_event_t gyro;
  sensors_event_t temp;
  lsm6ds3trc.getEvent(&accel, &gyro, &temp);

//  Serial.print("\t\tTemperature ");
//  Serial.print(temp.temperature);
//  Serial.println(" deg C");

  /* Display the results (acceleration is measured in m/s^2) */
//  Serial.print("\t\tAccel X: ");
//  Serial.print(accel.acceleration.x);
//  Serial.print(" \tY: ");
//  Serial.print(accel.acceleration.y);
//  Serial.print(" \tZ: ");
//  Serial.print(accel.acceleration.z);
//  Serial.println(" m/s^2 ");

  /* Display the results (rotation is measured in rad/s) */
//  Serial.print("\t\tGyro X: ");
//  Serial.print(gyro.gyro.x);
//  Serial.print(" \tY: ");
//  Serial.print(gyro.gyro.y);
//  Serial.print(" \tZ: ");
//  Serial.print(gyro.gyro.z);
//  Serial.println(" radians/s ");
//  Serial.println();

  delay(100);

  // serial plotter friendly format

  Serial.print(temp.temperature);
  Serial.print(",");

  Serial.print(accel.acceleration.x);
  Serial.print(","); Serial.print(accel.acceleration.y);
  Serial.print(","); Serial.print(accel.acceleration.z);
  Serial.print(",");

  Serial.print(gyro.gyro.x);
  Serial.print(","); Serial.print(gyro.gyro.y);
  Serial.print(","); Serial.print(gyro.gyro.z);
  Serial.println();
  delayMicroseconds(10000);
}

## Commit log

2024-11-08 Added files from Rev 1.0 and Arduino example files for I2C, IMU, and Analog Outputs
    [BOM for iotaCore.csv, Pick Place for iotaCore.csv, log.xlsx]
2024-11-24 Added Arduino Examples and image assets
2024-12-31 Adds Rev 2.0 Board design and assets directory
    [BOM for iotaCore.csv, Pick Place for iotaCore.csv, iotaCore-IO.SchDoc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]
2025-01-27 updated software and changed naming conventions to "tiny"
    [log.xlsx]
2025-02-21 Adds Enclosure Files
    [8P Screw Terminal.stp, Assem1.SLDASM, BlankIotaPCB.SLDPRT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]
2025-03-22 Cleaned up File Org. and Updated CAD files.
    [8P Screw Terminal.stp, BOM for iotaCore.csv, BlankIotaPCB.SLDPRT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]
2025-03-23 Updates Pin Legend
2025-08-21 Adds new revision of datasheet
    [Enclosure-Bottom.SLDPRT, Enclosure-Top.SLDPRT]

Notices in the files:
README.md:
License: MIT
